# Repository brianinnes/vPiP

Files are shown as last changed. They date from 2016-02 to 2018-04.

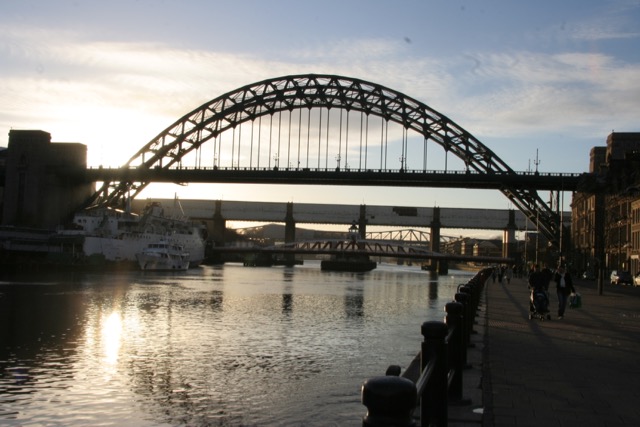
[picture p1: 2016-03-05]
testImages/TyneBridge.jpg

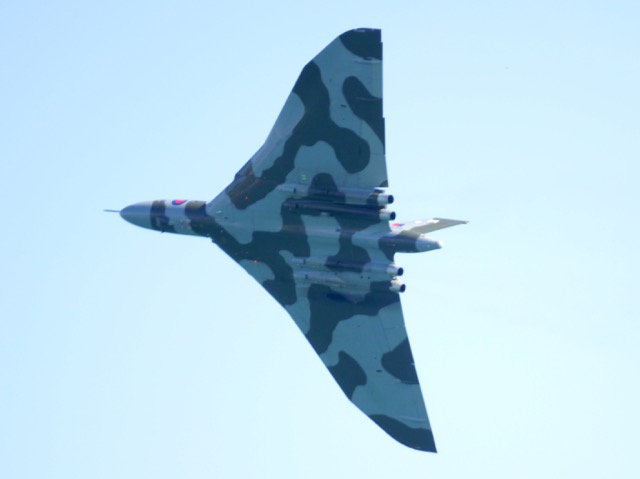
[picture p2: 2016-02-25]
testImages/Vulcan.jpg

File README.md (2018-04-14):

# vPiP
Driving a drawing machine from python

A python library targeted to run on a Raspberry Pi with accompanying Arduino code.  This code is intended to run on the driver board created by makeBournemouth

Links:  

- makeBournemouth [https://www.makebournemouth.com]()
- Controller board : [https://github.com/MarkJB/Eggbot-Spherebot-PyPlotter-Controller]()

Inspired by the Polargraph project [http://www.polargraph.co.uk]() and gocupi project [https://github.com/brandonagr/gocupi]()

To run this library you need Python installed with the Python Imaging Library fork, Pillow.  Installation instructions are here : [https://pillow.readthedocs.org/en/latest/installation.html]()  

sudo apt-get install libtiff5-dev libjpeg-dev zlib1g-dev libfreetype6-dev liblcms2-dev libwebp-dev tcl8.5-dev tk8.5-dev
pip install Pillow  

The C++ code for the Raspberry pi is build using Vagrant [https://www.vagrantup.com]() , which runs on most commonly used operating systems.

The make install command will automatically install the binary code on a Raspberry Pi, but relies on ssh auto login using a certificate.   
To setup auto login open a terminal and login to the vagrant build machine   
`vagrant up`   
`vagrant ssh`

Generate a certificate - on the raspberry pi:
`cd .ssh`   
`ssh-keygen -t rsa` accept all the default, DO NOT enter a password - leave blank     
`cat id_rsa.pub >> authorized_keys`  
`chmod 600 authorized_keys`  
`rm id_rsa.pub`  

Copy the certificate to the target Raspberry Pi using the following commands, replacing the host name (*raspberrypi.local*) with the host name or IP address of your pi:
`export REMOTE_PI=raspberrypi.local`   
`ssh pi@raspberrypi.local mkdir -p .ssh`   
`cat ~/.ssh/id_rsa | ssh pi@$REMOTE_PI 'cat >> .ssh/vagrant.rsa'`  
`ssh pi@$REMOTE_PI chmod 600 .ssh/vagrant.rsa`  
`ssh pi@$REMOTE_PI 'echo "Host vagrant" >> .ssh/config'`  
`ssh pi@$REMOTE_PI 'echo "Hostname vagrant.local" >> .ssh/config'`  
`ssh pi@$REMOTE_PI 'echo "IdentityFile ~/.ssh/vagrant.rsa" >> .ssh/config'`  

#Installing MQTT on a Raspberry Pi

You need an MQTT broker running and configured to run this software.  The MQTT broker can run on the Raspberry Pi.  To install run the following commands - this assumes running the latest Raspbian Stretch :  
- wget http://repo.mosquitto.org/debian/mosquitto-repo.gpg.key  
- sudo apt-key add mosquitto-repo.gpg.key  
- cd /etc/apt/sources.list.d/  
- sudo wget http://repo.mosquitto.org/debian/mosquitto-stretch.list
- sudo apt-get update
- sudo apt-get install -y mosquitto mosquitto-clients

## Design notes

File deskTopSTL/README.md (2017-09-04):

This folder contains the 3D printer files and information needed to build a desktop vPiP.  

The bill of materials is:  
- Raspberry Pi 3 model B  
- Built and populated [pi-2-stepper board](https://github.com/MarkJB/pi-2-stepper-board)  
- Arduino/Genuino compatible pro mini (ATmega 328p 3.3v 8MHz) - check PCB layout to ensure pro mini pins align with socket in PCB  
- Mini Servo - TowerPro SG90/92 or equivalent   
- 2 x ? Stepper drivers  
- ? voltage regulator  
- QTR-1RC Reflectance Sensor (pack of 2)  
- 2 x Stepper Motors (Nema 8 Bipolar 1.8º - 8HS11-0204S)  
- Vertical Blind, white plastic 2mm ball chain (2 meters)  
- A3 frameless whiteboard (297mm x 420mm x 4.5mm)  
- 6 x Bearings (603ZZ - 3mm x 9mm x 5mm)
- 12Volt (2A or higher) power supply

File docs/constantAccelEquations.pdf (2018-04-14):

## Control of stepper motors for vPiP drawing machine

This document sets out the approach for driving the stepper motors of the vPiP drawing machine within the architecture set out in the wiki. (https://github.com/brianinnes/vPiP/wiki/architecture)

The primary goal of the stepper driver to to produce a smooth motion to enable the fastest possible motion without making the print head start swinging or creating excessive movement within the cables driving the print head (which has been observed in existing implementations with v1 software).

In addition to the fast, smooth motion the algorithm should:
- keep the print head moving as fast as possible, reducing the loss of speed when transitioning between lines
- provide progress feedback to controlling process(es)
- allow interrupt commands to be sent to pause a drawing (say to allow a pen change), which will bring the drawing to a controlled stop at the end of a line, with the pen being raised from the paper (and optionally the drawing head homed). The drawing must be able to be resumed from exactly where it was paused.

## Kinematics - Algorithm for achieving smooth, fast motion

In version 1 of vPiP, the algorithm used constant acceleration to change velocity. This produces very high jerk values (rate of change of acceleration) at the transitions, which is a cause for stress on the system, which could be responsible for generation vibrations and additional movement in the control cables. To reduce the stress in the system and provide smoother motion of the print head then a constant jerk algorithm should be used.

Using Calculus to understand the equations of motion:
Looking at displacement (s) (distance travelled from start position s0):
- Velocity (v) is the first derivative of displacement with respect to time
- Acceleration (a) is the first derivative of velocity and the second derivative of displacement with respect to time (rate of change of velocity)
- Jerk (j) is the first derivative of acceleration and the third derivative of displacement with respect to time (rate of chance of acceleration)

Which gives us the kinematic equations:

Once the speed profile for the line has been calculated, then this needs to be translated into timer information to step each motor to create the line - this will be discussed later in the document.

Making each line a separate operation bringing the print head to a stop after each line is not ideal, so the algorithm also has to calculate the optimum speed to transition from 1 line to another. The angle between the lines will govern the amount of velocity that can be maintained during the transition and the appropriate amount of deceleration and acceleration should be calculated.

With short lines the acceleration/deceleration may take place over a number of line segments (such as curves implemented as a number of short line segments).

## s = s0 + v0t+ ¹

2 a0t

2

+ ¹
6 jt

3

## v = v0 + a0t+ ¹

2 jt

2

## a = a0 + jt

## Example data

With between motor driving wheels : | 344mm
Distance to top left corner of board : | x = 22mm; y = 36mm
Distance to paper location from top of board : | x = 10mm; y = 40mm
therefore distance from (0,0) measuring point = 22+10 ; 36 + 40 = (32mm, 76mm)
Paper Size = A4 portrait : | x = 210mm; y = 297mm,
therefore paper bottom right corner at 32 + 210; 76+297 = (242mm, 374mm) Paper margin = 10mm, so drawing area is (42mm, 86mm) to (232mm, 364mm)
Drawing grid is 10,000 along x and | along y
therefore1 point on the coordinate grid is
Maximum Velocity = 30 mm/ds (millimeters per decisecond : decisecond = 0.1 seconds) Maximum Acceleration = 10 mm/ds²
Maximum Jerk = 5 mm/ds³

Line in coordinates (100,9000) -> (9000,100)
Line in mm = (42+100*0.019, 86+9000*0.019) -> (42+9000*0.019, 86+100*0.019) = (43.9,257) -> (213,87.9)

Line length =

## Line Geometry

To calculate the formula for the line from (x1, y1)->(x2, y2):

where m is the gradient of the line and c is where the line crosses the x=0 axis (unless the line is vertical),

so if x1 ≠ x2:

Plugging in one of the coordinate (100, 9000):

To calculate a point (x, y) a specified distance (d) from the first point (x1, y1) along a line (x1, y1)→(x2, y2):

### 10000 * ²⁷⁷

190 = 14578.947
190
10000 = 0.019mm

## Δx² + Δy²

(213 − 43.9)

2 + (257 − 87.9)

2
169.1² + 169.1²
57189.62 = 239.1435mm

## y = m x + c

m = y2 − y1
x2 − x1

## y = m x + c y − m x = c c = y − m x

m = y2 − y1
x2 − x1
m = 100 − 9000

9000 − 100 = −8900
8900 = − 1

## c = y − m x

c = 100 − −1 * 9000 = 9100

x = x1− d * (x1 − x2)
linelength

## y = m x + c

## 7-phases for constant acceleration

Using constant jerk to control the rate of change of acceleration produces 7 stages for a line when the line needs to accelerate and decelerate and there is sufficient distance, velocity change and time to allow all 7 stages:

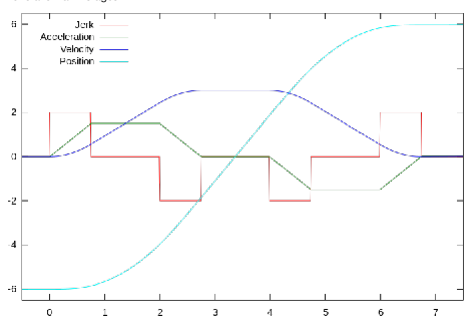
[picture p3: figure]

Acceleration time = ∆t1 + ∆t2 + ∆t3 Constant velocity time = ∆t4
Deceleration time = ∆t5 + ∆t6 + ∆t7

### Phase 1 - Increasing Acceleration

At t0:
j0 = jmax = 5
a0 = a0 = 0
v0 = v0 = 0
s0 = 0
| 1 = t0 → t 1 | Δt2 = t 1 → t2 | 3 t | Δt 4 = t3 → t 4 | 4 → t Δ 5 t3 = t2 → t Δ | Δt6 = t5 → t6 | Δt7 = t6 → t Δ 7 t5 = t
Jerk - j | j max | 0 | −j max | 0 | −j max | 0 | j max
Acceleration - a | increasing | amax | decreasing | 0 | increasing deceleration | −amax | decreasing deceleration
Velocity - v | increasing | increasing | increasing | vmax | decreasing | decreasing | decreasing
Displacement - s | increasing | increasing | increasing | increasing | increasing | increasing | increasing

Δt

## 1 = Δt3 = t

1 = amax
jmax

= 10
5 = 2

Note: at t = t1:

plugging in the sample numbers gives:

at end of phase (t1) we have:

### Phase 2 - Constant Acceleration

At t1
j1 = 0
a1 = amax
v1 = vt1 = 10 v2 = vmax - v1 = 30 - 10 = 20 s1 = st1 = 6.667

at end of phase (t2) we have:

## t0 < t ≤ t

1

## at = j

maxt

## vt = v0 + a0t+ ¹

2 j

maxt

2

## st = v0t+ ¹

2 a0t

2 + ¹
6 j

maxt

3

## v1 = v0+ a2

s
(2jmax)

## t0 < t ≤ t

1

## vt = 0 + 0t+ ¹

2 5t

2 = 5t2
2

## st = 0t+ ¹

2 0t

2 + ¹
6 5t

3 = 5t

3
6

## at1 = amax = 10mm /ds²

vt1 = 5t2

2 = 5 * 2²
2 = 20

## 2 = 10mm /ds

or

## vt1 = 0+ ¹⁰²

2 * 5 = 100
10 = 10

st1 = 5t

3

6 = 5 * 2³
6 = 40
6 = 6.667mm

## v2 = v1 + amaxΔt2 v2 − v1 = amaxΔt2

v2 − v1
amax

= Δt2

Δt2 = vmax − 2v1
amax
Δt2 = 30 − 2 * 10

10 = 30 − 20 10 = 1

t

1 < t ≤ t2

## vt = v1 + amaxt = 10 + 10t

## st = v1t+ ¹

| 2 amaxt

## 2 = 10t + ¹⁰

2 t

2 = 10t + 5t

2

### Phase 3 = Decreasing Acceleration

At t2:
j2 = -jmax
a2 = 10mm/ds²
v2 = 20mm/ds
s2 = s1 + ∆s2 = 6.667 + 14 = 20.667mm

plugging in the example numbers gives:

at the end of phase 3 we have :

### Phase 4 - Constant velocity

At t3:
j3 = 0
a3 = 0
v3 = vmax = 30mm/ds²
s3 = s1 +∆s2 +∆s3 = 6.667+15+33.333 = 55mm = Distance to accelerate to max velocity t3 = ∆t1+∆t2+∆t3 = 2+1+2 = 5ds = Time to accelerate to max velocity

With symmetric acceleration and deceleration, distance and time to decelerate will equal time to accelerate, so for phase 4, the constant velocity phase:

Distance to travel in phase 4 = Total Distance - 2*s3 = 239.1435-2*55 = 239.1435-110 = 129.1435

so plugging in the test data we have

## vt2 = 10 + 10 * 1 = 20mm /ds Δst2 = 10 * 1 + 5 * 1² = 10 + 5 = 15mm

## t2 < t ≤ t3 at = j

maxt

## vt = v2 + a2t+ ¹

2 j

maxt

2

## st = v2t +

1
2

a2t

2

+ ¹
6 j

maxt

3

## t0 < t ≤ t

1

## vt = 20 + 10t+ ¹

2 − 5t

## 2 = 20 + 10t − ⁵t2

2

## st = 20t+ ¹

2 10t

2 + ¹
6 5t

## 3 = 20t + ¹⁰

2 t

2 − ⁵t

3
6
at3 = 0

## vt3 = 20 + 10 * 2− ⁵ * 2²

2 = 20 + 20 − ²⁰

## 2 = 30mm /ds Δst3 = 20 * 2+ ¹⁰ * 2²

2 − ⁵ * 2³
6 = 40 + 20 − ⁴⁰
6 = 40 − 6.667 = 33.33mm

## t3 < t ≤ t

4
st = vmaxt

### Phase 5 - Increasing Deceleration

At t0:
j4 = -jmax
a4 = a4
v4 = v4
s4 = s4

### Phase 6 - Constant Deceleration

At t1
j1 = 0
a1 = amax
v1 = v1 v2 = vmax - v1
s1 = s1

### Phase 7 = Decreasing Deceleration

At t2:
j2 = jmax
a2 = amax
v2 = v2
s2 = s2

129.1435 = 30Δt
4
Δt

4 = 129.1435
30 = 4.3048ds

Δt

## 5 = Δt7 = t

5 = amax
jmax
t

4 < t ≤ t
5

## vt = v4 + a4t − 1

2 j

maxt

2

## st = v4t − 1

2

a4t

2 − 1
6 j

maxt

3

t

5 < t ≤ t6

## v2 = v1 + amaxΔt2 v2 − v1 = amaxΔt2

v2 − v1
amax

= Δt2

## Δt2 = vmax − 2v1

amax

## vt = v1 + amaxt

## st = v1t +

1
2

amaxt

2

### How to deal with short lines

The 7 phases defined above requires a line to be of a certain length to allow all 7 phases to run. As line become shorter then phase 4 will reduce until it no longer contributes to the movement, so the line becomes phases 1, 2, 3, 5, 6, 7. This is the shortest line that will reach maximum velocity from a standing start and coming to a stop at the end of the line.

If the line is shorter then phases 2 and 6 will reduce symmetrically, but this will reduce the velocity reached whilst drawing the line (maximum rate of acceleration will still be reached). As the line shortens then eventually phases 2 and 6 will contribute nothing to the line, so the line becomes phases 1, 3, 5, 7. This is the shortest line that will reach maximum acceleration from a standing start and coming to a stop at the end of the line.

If the line is still shorter then phases 1, 3, 5 and 7 will reduce symmetrically, but this will prevent maximum acceleration from being achieved whilst drawing the line.

## Combining multiple lines

It is not always desirable to start a line from stop and coming to a stop at the end of every line. It is often possible to combine lines to maintain some velocity during the transition from one line to the next. The angle between the lines determines how much velocity can be carried during the transition from one line to the next.

[See https://onehossshay.wordpress.com/2011/09/24/improving_grbl_cornering_algorithm/]

For a given angle θrad the maximum velocity is given by:

Given the 3 points that define 2 lines (x1, y1)->(x2, y2)->(x3, y3) that join at (x2, y2), you can use vectors to find the angle between the two lines.

## t6 < t ≤ t7 vt = v2 + a2t − 1

2 j

maxt

2

## st = v2t +

1
2

a2t

2 − 1
6 j

maxt

3

| t0 | t1 | t2 | t3 | t4 | t5 | t6 | t7
t (ds) | 0 | 2 | 3 | 5 | 9.3048 | 11.3048 | 12.3048 | 14.3048
a (mm/ds²) | 0 | 10 | 10 | 0 | 0 | -10 | -10 | 0
v (mm/ds) | 0 | 10 | 20 | 30 | 30 | 20 | 10 | 0
d (mm) | 0 | 6.667 | 21.667 | 55 | 184.1435 | 217.4768 | 232.4768 | 239.1435

vjunction = amaxR

## R = 1 − cos(θrad)

2

Note: | is the length of the vector , which is the length of the line (x1,y1)->(x2,y2) and is the length of the vector , which is the length of the line (x2,y2)->(x3,y3).

Combining the 2 formula removes the cos function:

Using this formula a number of line segments can be combined to form a continuous movement. The motion needs to come to a complete stop when the pen needs to be raised or when the angle between lines is too small. Whilst drawing the composite line any of the 7 phases may cross multiple line segments and there may need to be additional acceleration or deceleration phases within the composite line depending on line segment joint angles.

This requires a planning algorithm to:
- Combine individual lines into line segments
- Determine maximum joint velocities
- Map the composite line into a series of motion phases

### Map lines into a series of motion phases

Turning the line segments into one of the 7 phases of motion (as described above). For any line there are a number of possible options:

1. The initial and final velocities are low enough and there is sufficient distance to travel to go through all 7 phases
2. The initial velocity is too hight, so only time for phases 1 and 3 while accelerating
3. The final velocity is too high to go through all deceleration phases, so only phases 5 and 7.
4. The line is too short to allow phase 4 (max velocity may not be possible), phases 1,2,3,5,6,7
5. The line is too short to allow constant acceleration phases, only phases 1,3,5,7
6. The line is too short to accelerate to reach the final velocity. Only phases 1,3 or 1,2 and 3. The length will determine how near the final velocity can be attained, but the line may complete with a slower than planned maximum velocity.
7. The line is too short to decelerate to meet the required final velocity. The start velocity to meet then required final velocity to be reach needs to be calculated then the previous line needs to be altered to finish at the required lower velocity so the current line can decelerate to the required final velocity.

## u ⃗= (a1, b1), v ⃗= (a2, b2)

## a1 = x2 − x1, b1 = y2 − y1, a2 = x3 − x2, b2 = y3 − y2 cos(π − θrad) = ( u ⃗⋅ v ⃗)

(∥ u ∥⃗⋅∥ v ∥⃗)

## cos(θrad) = -1 * ( u ⃗⋅ v ⃗)

(∥ u ∥⃗⋅∥ v ∥⃗)
cos(θrad) = -1 * | (a1a2 + b1b2)
| ( a12 + b1 2 * a22 + b2

2)
∥ u ⃗∥ | u ⃗
∥ v ⃗∥ | v ⃗

vjunction = amax *

1 + (

(a1a2 + b1b2)

( a12 + b1

2 * a22 + b2

2)

)

2

## Turning the planned line into vPip movement

Up to now this document has focussed on calculating the motion for the lines. Once the lines have been planned and the set of motion phases has been calculated to create the lines this needs to be mapped into a set of stepper instructions for the 2 motors on a vPiP drawing machine. The planning and calculations required to create the motion phases is too complex for a small 8-bit processor, such as the Arduino that drives the steppers, so the computation is performed on the Raspberry Pi then a series of instructions is passed to the Arduino to control the stepper drivers.

There are a number of possible approaches for the communication between the Raspberry Pi and the Arduino. There may have to be a trade off between accuracy and maximum achievable data rate between the Raspberry Pi and the Arduino.

In version 2 there are options to look at using different communication mechanisms between the Raspberry Pi and the Arduino:
- Serial (UART)
- I²C - (cannot run at maximum speed, as there is a hardware bug in the Raspberry Pi, which the Arduino cannot cope with)
- SPI - (not enabled with the current version of the vPIP controller circuit board)

Other options that could be considered include modifying the module used to control the vPiP plotter (ESP32, NXP or ST Micro arm based module - these give 32-bit processing capability, so may remove the need to split the calculation and motor driving, or could leave the planning on the Pi or a laptop/workstation, but move the stepper calculations to the vPiP controller board)

These decisions need to be made up front as the outcome will define the vPiP controller board interface and API.

### Time Slicing

In version 1 of vPiP the Raspberry Pi to Arduino communication is based on a series of equal time slices, where the number of steps required for each motor is calculated and sent over the serial link to the Arduino. This produces an approximation of the calculated motion as for each time slice the required steps are spaced equally over the time rather than being at the exact calculated time interval.

Using time slices we have all the equations we need to determine the position the drawing head (displacement - s) should be at for each time slice interval, so for a given time t we can calculate the displacement (s) then calculate the coordinate in mm coordinate space. This can then be plugged into the equations that calculate the length of the control cables from each stepper motor moving the drawing head, and then from there the number of steps each motor should be at from the home position. The smaller the time slice the more accurate the step timing, but the higher the data rate between the Raspberry Pi and the Arduino.

### Fully accurate time steps

This is the most desirable outcome, as each stepper motor will be driven at exactly the correct time (allowing for CPU clock speed). For each step of each motor calculate the time the step should be taken, then combine the step times for each motor to create a stream of delays then step instructions (L step, R step or both step). This will require a high data rate (need to calculate) to pass these instructions to the stepper controller, and may need a high CPU clock speed on the controller to be able to parse the stream and implement the stepper controls.

One of the issues with this approach is the mathematics needed to calculate the time for each step, as phases 1, 3, 5 and 7 involve cubic equations, which need to be solved for t, as s, v, a and j will be known:

[TODO research algorithms for solving cubic functions - maybe https://stackoverflow.com/questions/1829330/solving-a-cubic-equation (https://stackoverflow.com/questions/1829330/solving-a-cubic-equation) or https://www.codeproject.com/Articles/798474/To-Solve-a-Cubic-Equation (https://www.codeproject.com/Articles/798474/To-Solve-a-Cubic-Equation) provides a solution?]

## st = v2t +

1
2

a2t

2

+ ¹
6 j

maxt

3

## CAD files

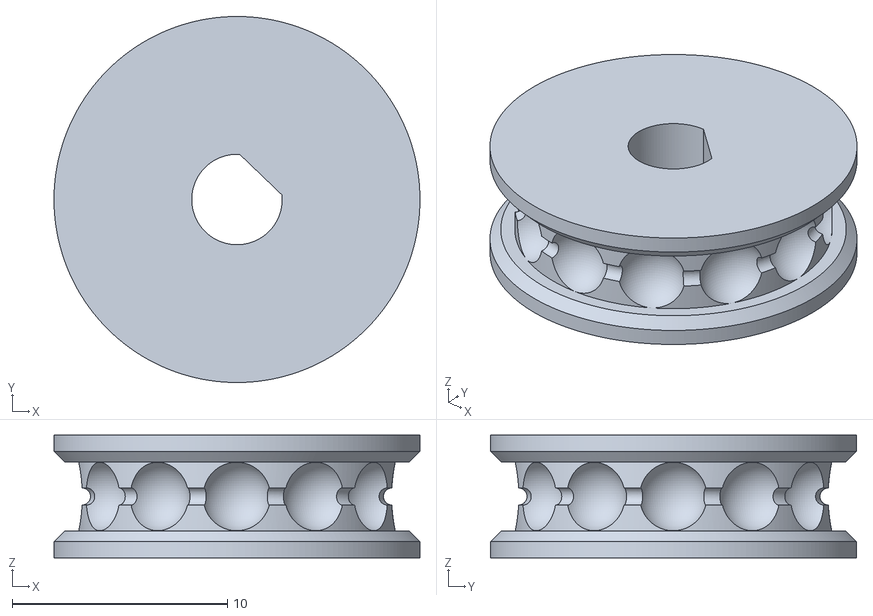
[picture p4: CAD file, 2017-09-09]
deskTopSTL/Motor cog (1).stl
17.0 x 17.0 x 5.69

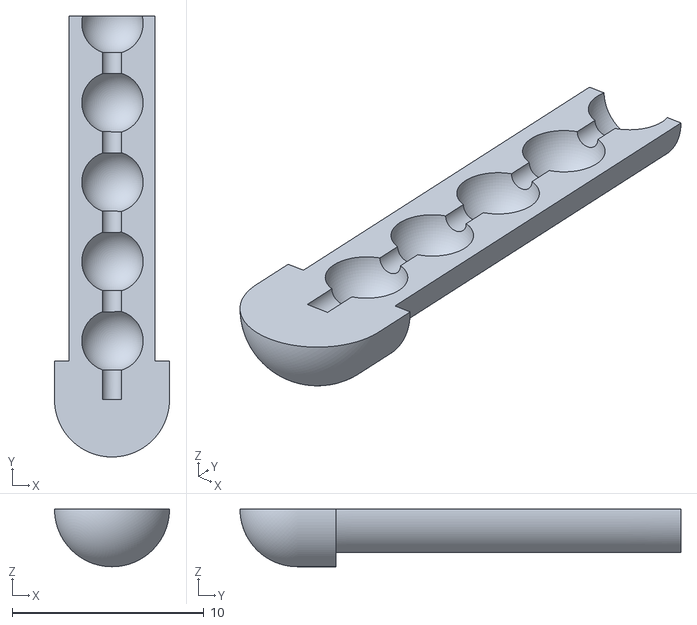
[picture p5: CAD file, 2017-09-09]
deskTopSTL/HangarCableGrab.stl
6.00 x 23.0 x 3.00

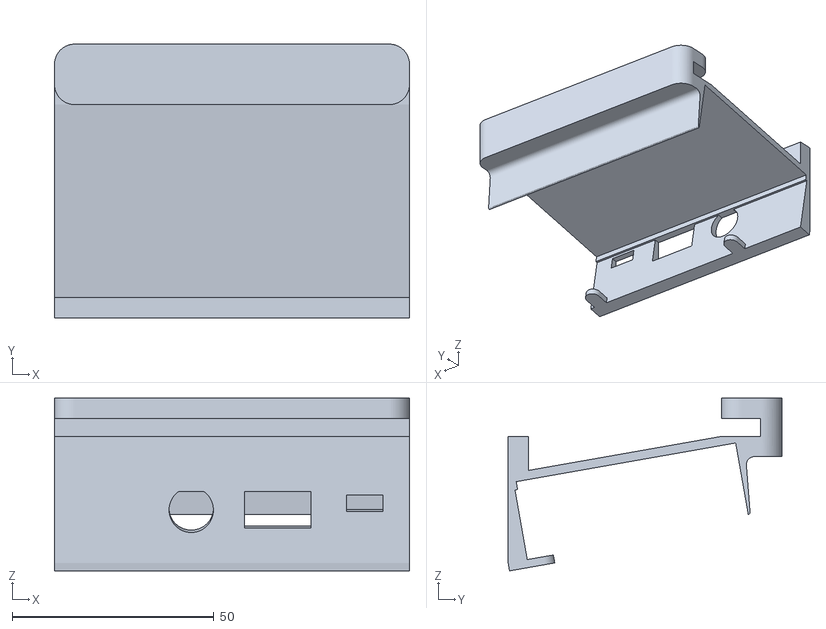
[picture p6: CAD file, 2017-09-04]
deskTopSTL/Pi Holder.stl
88.0 x 67.9 x 42.8

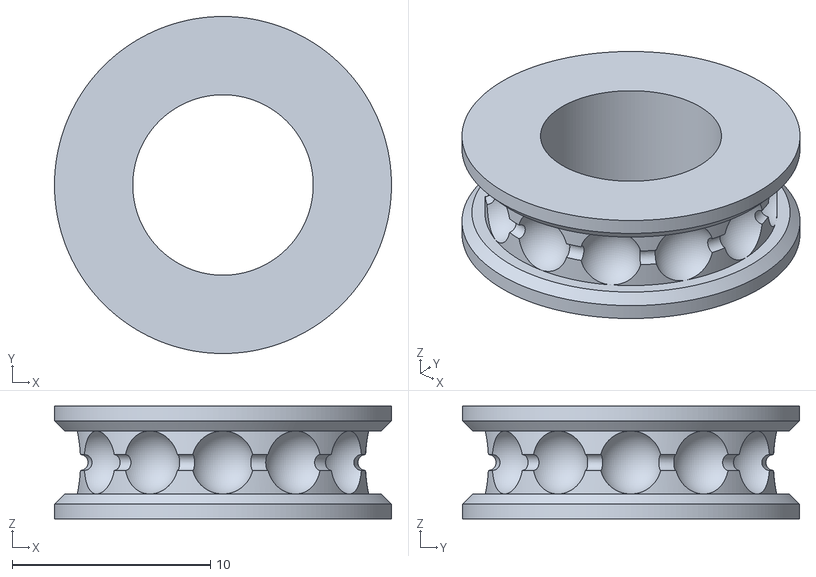
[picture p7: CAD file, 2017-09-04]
deskTopSTL/BearingPullyWheel.stl
17.0 x 17.0 x 5.69

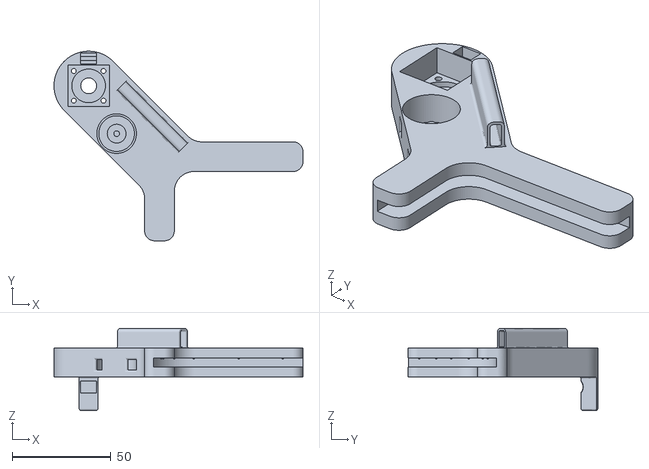
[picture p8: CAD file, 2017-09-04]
deskTopSTL/TopRArmBearing.stl
125.8 x 95.8 x 41.5

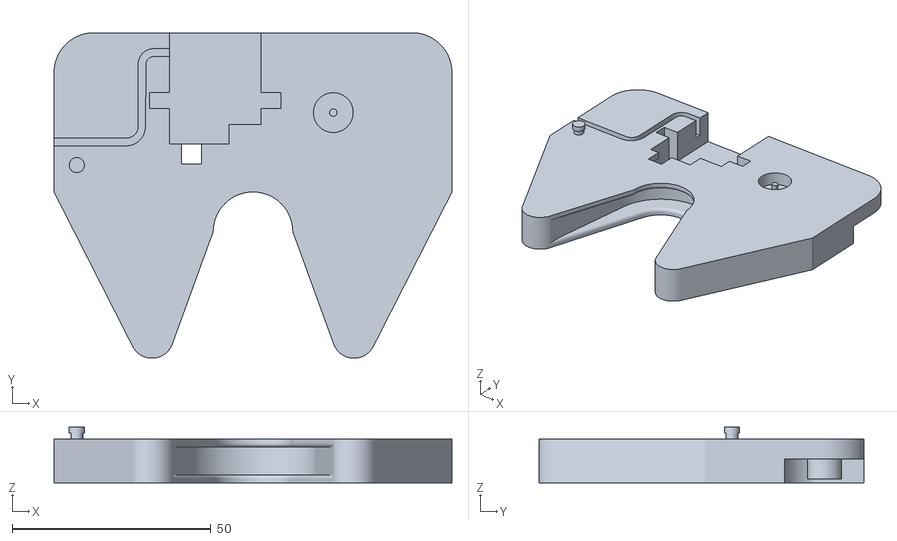
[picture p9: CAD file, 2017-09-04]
deskTopSTL/GondolaBody.stl
100.0 x 81.8 x 14.0

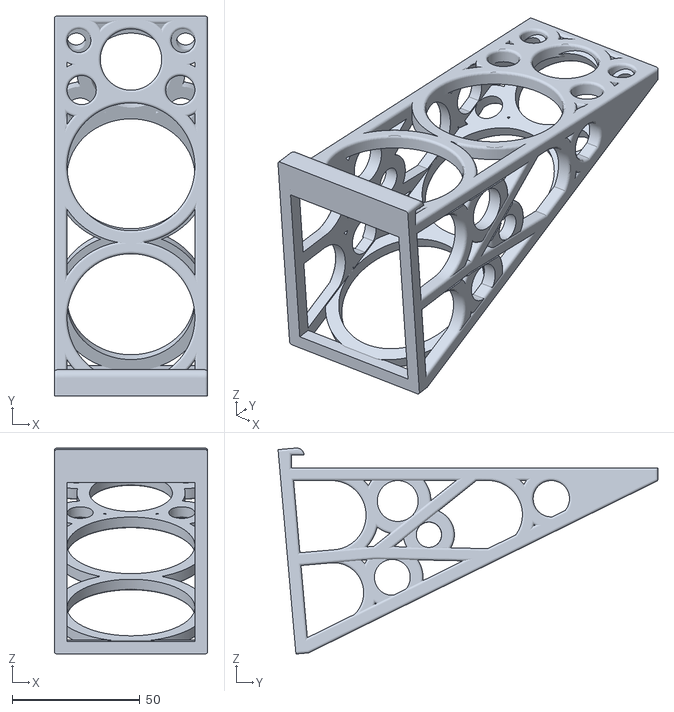
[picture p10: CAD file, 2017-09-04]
deskTopSTL/Stand.stl
60.0 x 148.7 x 80.6

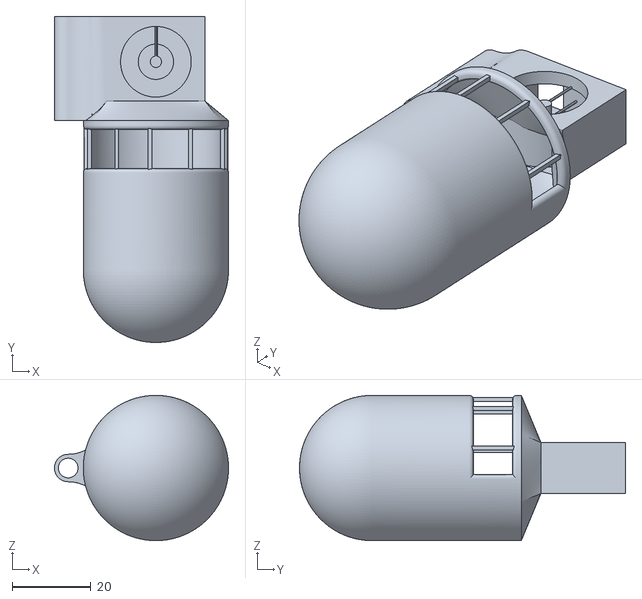
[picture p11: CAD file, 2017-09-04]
deskTopSTL/HangarLeftBearing.stl
44.3 x 83.0 x 37.0

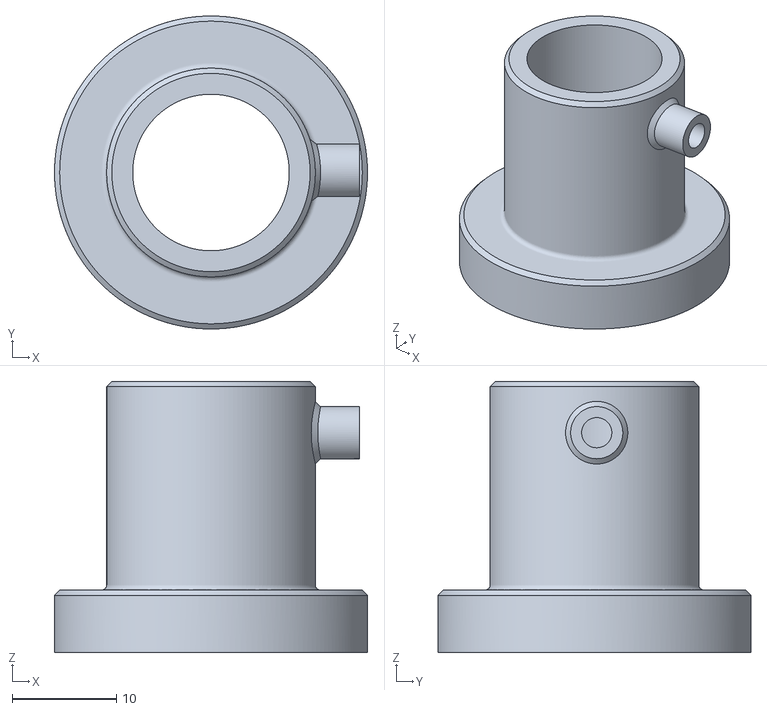
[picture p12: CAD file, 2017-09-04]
deskTopSTL/PenHolder (1).stl
30.0 x 30.0 x 26.0

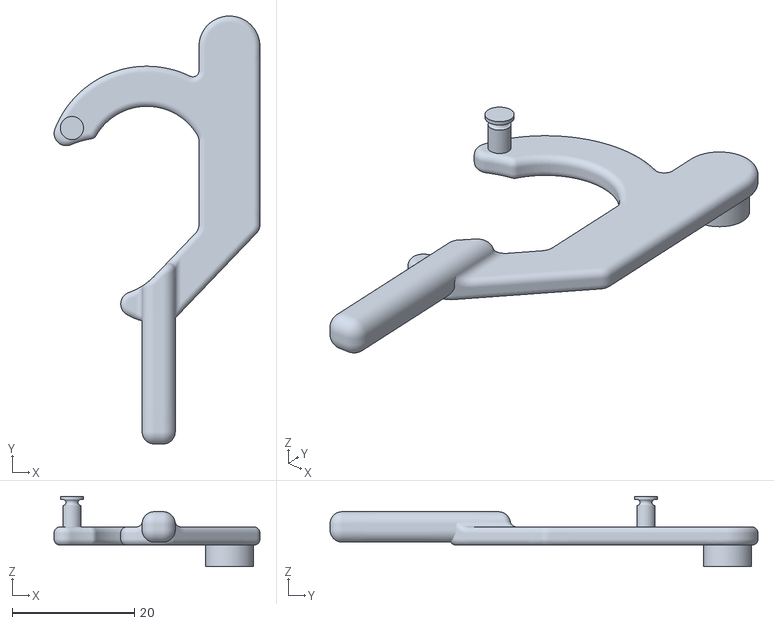
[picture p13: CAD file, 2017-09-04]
deskTopSTL/PenHolderClamp.stl
33.7 x 70.1 x 11.5

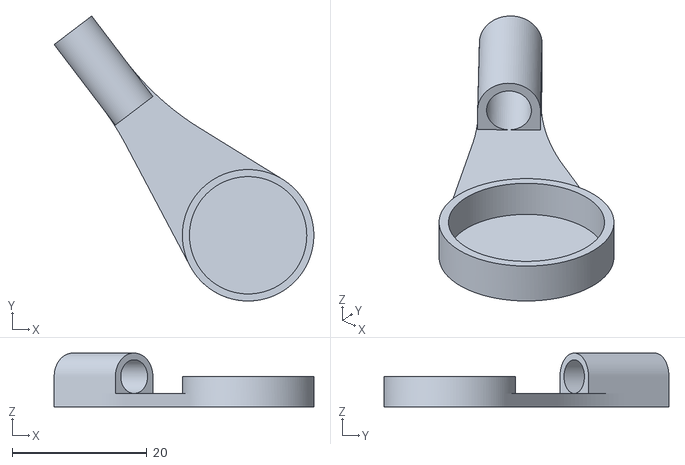
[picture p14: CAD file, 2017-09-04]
deskTopSTL/CordArm.stl
38.5 x 42.3 x 8.00

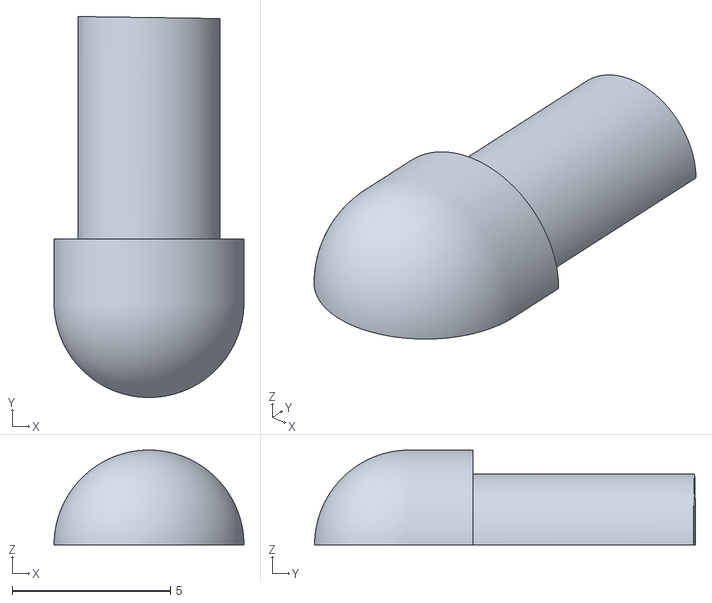
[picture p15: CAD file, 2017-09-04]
deskTopSTL/CableGrab] (1).stl
6.00 x 12.0 x 3.00

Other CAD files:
deskTopSTL/TopLeftArmBearing.stl
deskTopSTL/HangarRightBearing.stl

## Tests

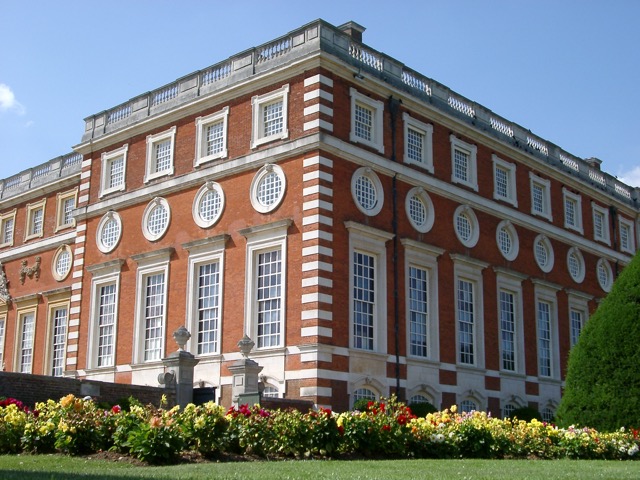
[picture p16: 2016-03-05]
testImages/HamptonCourt.jpg

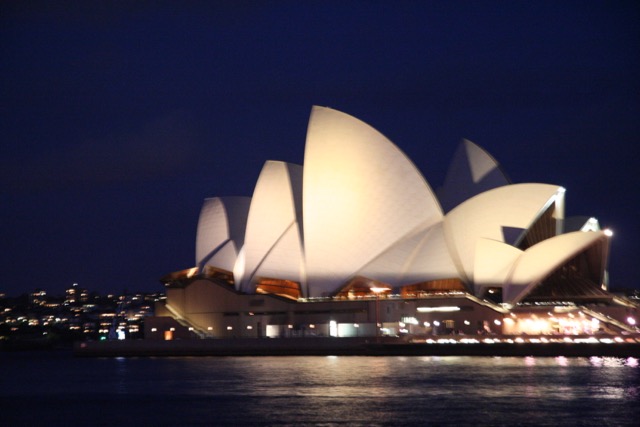
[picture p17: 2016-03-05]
testImages/SydneyOperaNight.jpg

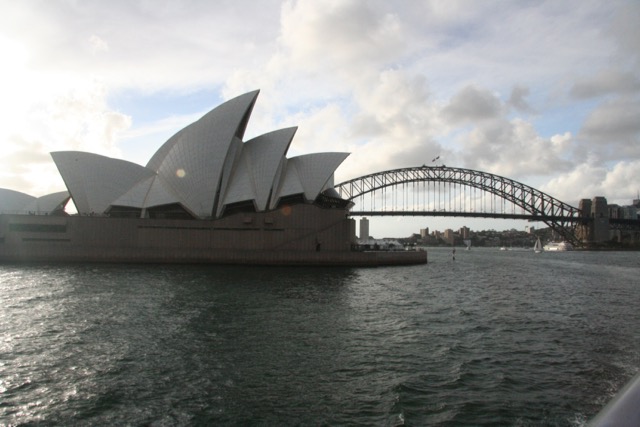
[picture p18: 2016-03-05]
testImages/SydneyOpera.jpg

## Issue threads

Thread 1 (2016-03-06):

Servo height settings are ignored

MarkJB, 2016-03-06:
Running test2.py and modifying the config values for penUp and penDown doesn't appear to have any effect on where the servo goes.

I tried a range of values but it doesn't change the servo positions.

I set them both to 0 and its still the same.

I changed the values in the Arduino firmware from:

`const long PENUP_ANGLE = 170;
const long PENDOWN_ANGLE = 85;`

to

`const long PENUP_ANGLE = 125;
const long PENDOWN_ANGLE = 63;`

and the positions changed.

This was with Python 2.7.11 on Win7x64

MarkJB, 2016-03-06:
I don't know why there aren't line breaks in the above... Markdown never works properly for me.

MarkJB, 2016-03-06:
If you are wondering the python is seeing the config:

C:\Users\Mark\Documents\GitHub\pycupi\python>c:\Python\Python27-11\python.exe test2.py
Polargraph __init__
Config is being read from C:\Users\Mark/.polargraph/config.cfg

***** System configuration *****
configured = True
penSize = 0.5
machineWidth = 610
machineHeight = 1010
mmPerRev = 92.0
stepsPerRev = 200
stepMultiplier = 8
serialPort = COM10
timeSliceUS = 2048.0
baud = 57600
motorAccel = 0.2
motorMaxSpeed = 100.0
penUp = 0
penDown = 0
homeX = 305
homeY = 120
polarDraw = True
size = A3p
width = 420
height = 297
posX = 83
posY = 398
margin = 20
pixelsX = 5000
pixelsY = 3381
rotate = False
stepsSizeMM = 0.0575
stepsPerValue = 15.75
MaxSpeedMMs = 100.0
AccelerationMMs2 = 500.0
screenX = 5000
screenY = 3381
showImage = False
saveImage = False
Coord handler running

Step handler running
Connected to Polargraph

Polargraph __exit__

brianinnes, 2016-03-06:
Ah, I forgot about this - it is on the todo list.  The gocupi protocol currently does not provide any options to send config data from the controlling device to the Arduino.  I have a cunning plan to use the reset command to be able send additional config data whilst still being able to run against a true gocupi system (where the config for micro-steps, timing window and penup/pen down angles all need to be set in Arduino code, and where applicable also in the controller code).

brianinnes, 2017-09-10:
Implemented in v0.2 in commit 37af6e78de0516c9e5431b9141468f667e025eab

MarkJB, 2017-09-10:
Liking the config!

Very cool that you can define the hardware pins from the controller rather than the firmware.

Am I right in thinking the config is extensible just be virtue of adding items to the config stuct and then send the relevant data (in order)?

brianinnes, 2017-09-10:
Yes, so long as the structure on the Pi and the Arduino are kept in sync you can add additional attributes and they will be sent to the Arduino on startup - the entire structure is sent to the Arduino.

You need to be aware of the structure packing differences between 64 and 8 bit architectures - hence the pack compiler instruction.

MarkJB, 2017-09-11:
One thing just struck me, https://github.com/brianinnes/vPiP/issues/16 says v2 must work with existing hardware which would mean being able to use serial if I2C isn't available/connected.

Closed 2017-09-10.

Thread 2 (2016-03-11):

Python processes don't die

MarkJB, 2016-03-11:
I was running test1.py and had to kill it (ctrl-c a couple of times) which left two processes running.

A second run of test1.py was killed leaving another 2 processes.

Had to kill them manually.

I was running commit:

f0d0eef793cf2f2e25163ef0d5ac13d7b2944c05
Date:   Wed Mar 9 21:28:13 2016 +0000
Moved from using threads to use multiprocesses to get round single process restriction and enable use of multi-core raspberry pi

brianinnes, 2017-04-27:
Version 2 will replace the need for multiple python processes

Closed 2017-04-27.

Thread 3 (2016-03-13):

Steppers are glitchy when setShowDrawing & setPlotting are both True

MarkJB, 2016-03-13:
Running test1.py with:

```
p.setShowDrawing(True)
#p.setSaveDrawing(True)
p.setPlotting(True)
```

or

```
#p.setShowDrawing(True)
p.setSaveDrawing(True)
p.setPlotting(True)
```

This doesn't happen if just have setPlotting true.

The steppers are stop start and there is lots of output on the console.

I captured some (below) and in doing so caused a keyboard interrupt (ctrl-c) and the output stopped and the steppers started working normally.

Step handler thread exception : <type 'exceptions.OSError'>
  File "/home/pi/pycupi/python/Pylargraph/serialHandler.py", line 106, in _stepHandlerThread
    dataRead = self.serialPort.read()
  File "/usr/lib/python2.7/dist-packages/serial/serialposix.py", line 453, in read
    buf = os.read(self.fd, size-len(read))
Step handler thread exception : <type 'exceptions.OSError'>
  File "/home/pi/pycupi/python/Pylargraph/serialHandler.py", line 106, in _stepHandlerThread
    dataRead = self.serialPort.read()
  File "/usr/lib/python2.7/dist-packages/serial/serialposix.py", line 453, in read
    buf = os.read(self.fd, size-len(read))
Step handler thread exception : <type 'exceptions.OSError'>
  File "/home/pi/pycupi/python/Pylargraph/serialHandler.py", line 106, in _stepHandlerThread
    dataRead = self.serialPort.read()
  File "/usr/lib/python2.7/dist-packages/serial/serialposix.py", line 453, in read
    buf = os.read(self.fd, size-len(read))
Step handler thread exception : <type 'exceptions.OSError'>
  File "/home/pi/pycupi/python/Pylargraph/serialHandler.py", line 106, in _stepHandlerThread
    dataRead = self.serialPort.read()
  File "/usr/lib/python2.7/dist-packages/serial/serialposix.py", line 453, in read
    buf = os.read(self.fd, size-len(read))
Step handler thread exception : <type 'exceptions.OSError'>
  File "/home/pi/pycupi/python/Pylargraph/serialHandler.py", line 106, in _stepHandlerThread
    dataRead = self.serialPort.read()
  File "/usr/lib/python2.7/dist-packages/serial/serialposix.py", line 453, in read
    buf = os.read(self.fd, size-len(read))
Step handler thread exception : <type 'exceptions.OSError'>
  File "/home/pi/pycupi/python/Pylargraph/serialHandler.py", line 106, in _stepHandlerThread
    dataRead = self.serialPort.read()
  File "/usr/lib/python2.7/dist-packages/serial/serialposix.py", line 453, in read
    buf = os.read(self.fd, size-len(read))
Step handler thread exception : <class 'serial.serialutil.SerialException'>
  File "/home/pi/pycupi/python/Pylargraph/serialHandler.py", line 106, in _stepHandlerThread
    dataRead = self.serialPort.read()
  File "/usr/lib/python2.7/dist-packages/serial/serialposix.py", line 460, in read
    raise SerialException('device reports readiness to read but returned no data (device disconnected?)')
Step handler thread exception : <class 'serial.serialutil.SerialException'>
  File "/home/pi/pycupi/python/Pylargraph/serialHandler.py", line 106, in _stepHandlerThread
    dataRead = self.serialPort.read()

If setPlotting() should never be true when setShowDrawing() or setSaveDrawing() are True - can this not be done automatically?

brianinnes, 2017-04-27:
fixed with #13

Closed 2017-04-27.

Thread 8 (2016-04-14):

Arduino Motorshield v2.3

5p4m3r, 2016-04-14:
Hi,
I am trying to get your stepperdriver sketch to work with the arduino motorshield v2.3.
and i am stuck. Obviously I am missing something very basic, but since i am new to python and arduino so i should start asking.
I hope it is the right spot if not just point me to the right direction.

so here is my sketch:

`//ADAFRUIT_MOTORSHIELD_V2.3`
```
#include <Wire.h>
#include <Adafruit_MotorShield.h>
#include <Adafruit_PWMServoDriver.h>
#include <AccelStepper.h>

const int stepType = MICROSTEP;

Adafruit_MotorShield AFMS = Adafruit_MotorShield();
Adafruit_StepperMotor *afMotorAleft = AFMS.getStepper(200, 1); //left M1 M2
Adafruit_StepperMotor *afMotorBright = AFMS.getStepper(200, 2); //right M3 M4

void forwarda() { afMotorAleft->onestep(FORWARD, stepType); }
void backwarda() { afMotorAleft->onestep(BACKWARD, stepType); }
void forwardb() { afMotorBright->onestep(FORWARD, stepType); }
void backwardb() { afMotorBright->onestep(BACKWARD, stepType); }
AccelStepper motorA(forwarda, backwarda);
AccelStepper motorB(forwardb, backwardb);

// comment out to disable PENUP support
#define ENABLE_PENUP

// Constants and global variables
// --------------------------------------
const int LED_PINS_COUNT = 4;
const int LED_PINS[LED_PINS_COUNT] = {
  10,11,12,13}; // the pins of all of the leds, first 3 are status lights, 4th is receive indicator

#ifdef ENABLE_PENUP
#include <Servo.h>
Servo penUpServo;
char penTransitionDirection; // -1, 0, 1
const long PENUP_TRANSITION_US = 524288; // time to go from pen up to down, or down to up
const int PENUP_TRANSITION_US_LOG = 19; // 2^19 = 524288
const long PENUP_COOLDOWN_US = 1250000;
const long PENUP_ANGLE = 170;
const long PENDOWN_ANGLE = 85;
#endif

const unsigned int TIME_SLICE_US = 2048; // number of microseconds per time step
const unsigned int TIME_SLICE_US_LOG = 11; // log base 2 of TIME_SLICE_US
const unsigned int POS_FACTOR = 8; // fixed point factor each position is multiplied by
const unsigned int POS_FACTOR_LOG = 3; // log base 2 of POS_FACTOR, used after multiplying two fixed point numbers together

const char RESET_COMMAND = 0x80; // -128, (128) command to reset
const char PENUP_COMMAND = 0x81; // -127, (129) command to lift pen
const char PENDOWN_COMMAND = 0x7F; // 127,(127) command to lower pen

const unsigned int MOVE_DATA_CAPACITY = 1024;
char moveData[MOVE_DATA_CAPACITY]; // buffer of move data, circular buffer
unsigned int moveDataStart = 0; // where data is currently being read from
unsigned int moveDataLength = 0; // the number of items in the moveDataBuffer
unsigned int moveDataRequestPending = 0; // number of bytes requested

char leftDelta, rightDelta; // delta in the current slice
long leftStartPos, rightStartPos; // start position for this slice
long leftCurPos, rightCurPos; // current position of the spools

unsigned long curTime; // current time in microseconds
unsigned long sliceStartTime; // start of current slice in microseconds

// setup
// --------------------------------------
void setup() {
  Serial.begin(57600);
  Serial.setTimeout(0);

//ADAFRUIT_MOTORSHIELD_V2.3
  AFMS.begin();  // create with the default frequency 1.6KHz

  // setup pins
  for(int ledIndex = 0; ledIndex < LED_PINS_COUNT; ledIndex++) {
    pinMode(LED_PINS[ledIndex], OUTPUT);
    digitalWrite(LED_PINS[ledIndex], HIGH);
  }

#ifdef ENABLE_PENUP
  penUpServo.attach(9);
  penUpServo.write(PENUP_ANGLE);
  delay(1000);
  penUpServo.write(PENDOWN_ANGLE);
  delay(1000);
  penUpServo.write(PENUP_ANGLE);
#endif

  ResetMovementVariables();

  delay(500);
  UpdateReceiveLed(false);
  UpdateStatusLeds(0);
}

// Reset all movement variables
// --------------------------------------
void ResetMovementVariables()
{
  leftDelta = rightDelta = leftStartPos = rightStartPos = leftCurPos = rightCurPos = 0;
  sliceStartTime = curTime;

#ifdef ENABLE_PENUP
  penTransitionDirection = 0;
  penUpServo.write(PENUP_ANGLE);
#endif
}

// Main execution loop
// --------------------------------------
void loop() {
  curTime = micros();
  if (curTime < sliceStartTime) { // protect against 70 minute overflow
    sliceStartTime = 0;
  }

  long curSliceTime = curTime - sliceStartTime;

#ifdef ENABLE_PENUP
  if (penTransitionDirection) {
    UpdatePenTransition(curSliceTime);
    if (!penTransitionDirection) {
      sliceStartTime = curTime;
    }
  } else {
#endif
    // move to next slice if necessary
    while(curSliceTime > TIME_SLICE_US) {
      SetSliceVariables();
      curSliceTime -= TIME_SLICE_US;
      sliceStartTime += TIME_SLICE_US;

#ifdef ENABLE_PENUP
      if (penTransitionDirection) {
        sliceStartTime = curTime;
        return;
      }
#endif
    }

    UpdateStepperPins(curSliceTime);
#ifdef ENABLE_PENUP
  }
#endif

  ReadSerialMoveData();
  RequestMoreSerialMoveData();
}

// Update stepper pins
// --------------------------------------
void UpdateStepperPins(long curSliceTime) {
  long leftTarget = ((long(leftDelta) * curSliceTime) >> TIME_SLICE_US_LOG) + leftStartPos;
  long rightTarget = ((long(rightDelta) * curSliceTime) >> TIME_SLICE_US_LOG) + rightStartPos;

  int leftSteps = (leftTarget - leftCurPos) >> POS_FACTOR_LOG;
  int rightSteps = (rightTarget - rightCurPos) >> POS_FACTOR_LOG;

  boolean leftPositiveDir = true;
  if (leftSteps < 0) {
    leftPositiveDir = false;
    leftSteps = -leftSteps;
  }
  boolean rightPositiveDir = true;
  if (rightSteps < 0) {
    rightPositiveDir = false;
    rightSteps = -rightSteps;
  }

  do {
    if (leftSteps) {
      forwarda();                        // changed the function
      if (leftPositiveDir) {
        leftCurPos += POS_FACTOR;
      } else {
        leftCurPos -= POS_FACTOR;
      }
      leftSteps--;

      UpdateStatusLeds(leftCurPos >> 13);
    }

    if (rightSteps) {
      forwardb();                        // changed the function
      if (rightPositiveDir) {
        rightCurPos += POS_FACTOR;
      } else {
        rightCurPos -= POS_FACTOR;
      }
      rightSteps--;
    }

    if (leftSteps || rightSteps) {
      delayMicroseconds(50); // delay a small amount of time before refiring the steps to smooth things out
    } else {
      break;
    }
  } while(true);
}

// Update pen position
// --------------------------------------
#ifdef ENABLE_PENUP
void UpdatePenTransition(long curSliceTime) {

  //int targetAngle = ((float)(PENDOWN_ANGLE - PENUP_ANGLE) * ((float)curSliceTime / (float)PENUP_TRANSITION_US)) + PENUP_ANGLE;
  //if (targetAngle > PENDOWN_ANGLE) {
    //targetAngle = PENDOWN_ANGLE;

    if (curSliceTime > PENUP_COOLDOWN_US) {
      penTransitionDirection = 0; // are done moving the pen servo
    }
  //}

  if (penTransitionDirection == 1) {
	//targetAngle = 180 - targetAngle;
    penUpServo.write(PENUP_ANGLE);
  } else if (penTransitionDirection == -1) {
    penUpServo.write(PENDOWN_ANGLE);
  }

  //penUpServo.write(targetAngle);
}
#endif

// Update status leds
// --------------------------------------
void UpdateStatusLeds(int value) {
  // output the time to the leds in binary
  digitalWrite(LED_PINS[0], value & 0x1);
  digitalWrite(LED_PINS[1], value & 0x2);
  digitalWrite(LED_PINS[2], value & 0x4);
}

// Update receive leds
// --------------------------------------
void UpdateReceiveLed(boolean value) {
  digitalWrite(LED_PINS[3], value);
}

// Set all variables based on the data currently in the buffer
// --------------------------------------
void SetSliceVariables() {
  // set slice start pos to previous slice start plus previous delta
  leftStartPos = leftStartPos + long(leftDelta);
  rightStartPos = rightStartPos + long(rightDelta);

  if (moveDataLength < 2) {
    leftDelta = rightDelta = 0;
  } else {
    leftDelta = MoveDataGet();
    rightDelta = MoveDataGet();

#ifdef ENABLE_PENUP
    if (leftDelta == PENUP_COMMAND) {
      leftDelta = rightDelta = 0;
      penTransitionDirection = 1;
    } else if (leftDelta == PENDOWN_COMMAND) {
      leftDelta = rightDelta = 0;
      penTransitionDirection = -1;
    }
#else
    if (leftDelta == PENUP_COMMAND || leftDelta == PENDOWN_COMMAND) {
       leftDelta = rightDelta = 0;
    }
#endif
  }
}                                                                                                                                                                                                                                                                                                                                                                                                                                                                                                                                                                                                                                                                                                                                                                                                                                                                                                                                                                                                                                                                                                                                                                                                                                                                                                                                                                                                                                                                                                                                                                                                                                                                                                                                                                                                                                                                                                                                                                                                                                            

// Stop everything and blink the status led value times
// --------------------------------------
void Blink(char value) {
 int counts = value;
  if (counts<0) counts=-counts;

  UpdateReceiveLed(false);
  for(int i=0;i<counts;i++) {
   delay(1000);
   UpdateReceiveLed(true);
   delay(1000);
   UpdateReceiveLed(false);

  }
  delay(100000);
}

// Read serial data if its available
// --------------------------------------
void ReadSerialMoveData() {

  if(Serial.available()) {
    char value = Serial.read();

    // Check if this value is the sentinel reset value
    if (value == RESET_COMMAND) {
      ResetMovementVariables();
      moveDataRequestPending = 0;
      moveDataLength = 0;
      UpdateReceiveLed(false);
      return;
    }

    MoveDataPut(value);
    moveDataRequestPending--;

    if (!moveDataRequestPending) {
      UpdateReceiveLed(false);
    }
  }
}

// Put a value onto the end of the move data buffer
// --------------------------------------
void MoveDataPut(char value) {
  int writePosition = moveDataStart + moveDataLength;
  if (writePosition >= MOVE_DATA_CAPACITY) {
    writePosition = writePosition - MOVE_DATA_CAPACITY;
  }

  moveData[writePosition] = value;

  if (moveDataLength == MOVE_DATA_CAPACITY) { // full, overwrite existing data
    moveDataStart++;
    if (moveDataStart == MOVE_DATA_CAPACITY) {
      moveDataStart = 0;
    }
  }
  else {
    moveDataLength++;
  }
}
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
brianinnes, 2016-04-14:
This is not a bug in the project code, so I am closing the issue.  I've not got a motor shield, but a quick web search shows it uses pins D12 & D13 for the direction control and D3 and D11 for the steps.  Your sketch configures the LED pins as 10, 11, 12 and 13 which will conflict with the motor control pins?

Closed 2016-04-14.

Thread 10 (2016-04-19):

Units should be in mm

MarkJB, 2016-04-19:
This is an Enhancement request. Might be irrelevant in light of the pending work, but raising it anyway as it is worth some consideration.

It is difficult to work in pixels when using multiple machines with different page sizes.

It would make life easier if units were in mm.

brianinnes, 2016-04-19:
In the config just set the pixels value to the same as the paper width (in mm) then the measurements are in mm.

MarkJB, 2016-04-19:
Does that not affect the 'resolution' of the pixels?

brianinnes, 2016-04-19:
depends.  If you always make the pixel size 1 mm square (pixel size in line with the paper size), then the number of pixels in each direction will change as paper size changes.  If you leave the pixel size the same across all the different paper size, then each paper size will have a scaled pixel size, but there will be the same number of pixels across the page.

Current implementation allows either way of working, but some of my test apps assume a 5000 pixel width.

Closed 2016-04-19.

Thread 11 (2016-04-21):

Default servo settings nearly cooked a servo

MarkJB, 2016-04-21:
I uploaded the vPiP arduino/stepper firmware to a pro mini and the servo did the usual up-down-up move. After a few minutes the servo was too hot to touch. I think the default values had this servo straining against its mechanical limits.

I'm wondering if this was what cooked the servo and arduino on the middle machine in the library.

Need to have default servo values that are nearer the middle of the range and with less travel between them to avoid risking damage.

brianinnes, 2017-09-11:
Fixed in v2 : The servo limits are no longer hard coded in the Arduino firmware.  Values can be set on the Pi and are sent to the Arduino at startup. 37af6e78de0516c9e5431b9141468f667e025eab

Closed 2017-09-11.

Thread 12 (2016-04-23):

Have to reset Arduino to get things working (vPiP board v1.0b)

MarkJB, 2016-04-23:
When I run vPiP (python test1.py) on a vPiP board v1.0b, the program sits at Polargraph exit until I reset the Arduino Pro Mini at which point the servo does its down-up-down move and then the steppers work...

I opened this against the vPiP board, but have done some debugging on the Arduino firmware and I think the issue is on the vPiP software side, so creating new issue here.

https://github.com/MarkJB/pi-2-stepper-board/issues/6

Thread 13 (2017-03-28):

Glitchy, stop/start steppers

MarkJB, 2017-03-28:
I thought this was only affecting my machine, but we were seeing this at the last meetup on another machine.

The steppers are stop-start with the following error repeatedly shown on the console:

Step handler thread exception : <class 'serial.serialutil.SerialException'>
  File "/home/mark/Documents/github/vPiP/python/vPiP/serialHandler.py", line 106, in _stepHandlerThread
    dataRead = self.serialPort.read()
  File "/usr/lib/python2.7/dist-packages/serial/serialposix.py", line 495, in read
    raise SerialException('device reports readiness to read but returned no data (device disconnected or multiple access on port?)')

I'm also seeing this when run from Linux Mint 18.1

I found the issue mentioned here: https://github.com/pyserial/pyserial/issues/17

MarkJB, 2017-03-29:
If I use alt:///dev/usbX?class=VTIMESerial then the errors stop, but the steppers are still glitchy...

I changed the following:
`#from serial import Serial`
`import serial`

`    def connect(self):`
`        # self.serialPort = Serial(self.config.serialPort, self.config.baud, timeout=10)`
`        self.serialPort = serial.serial_for_url('alt://' + self.config.serialPort + '?class=VTIMESerial', timeout=10)`
`        self.serialPort.baudrate = self.config.baud`

I'm also seeing two instances of `Starting stepHandlerThread` ?!?

`Starting stepHandlerThread`
`Connected to Vpip`
`Starting stepHandlerThread`
`Connected to Vpip`
`Vpip __exit__`

MarkJB, 2017-04-18:
The issue wasn't pyserial, it was due to multiple serial processes starting up.

One created by a line in the config: polardraw = True
The other in the calling python script: p.setPlotting(True)

Added Brians 'on the fly' fix in commit 153e3c0b294d1045a9eb5ccc3e128b42176718a8

Closed 2017-04-18.

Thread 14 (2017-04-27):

Define v2 architecture

brianinnes, 2017-04-27:

brianinnes, 2017-04-27:
Need to be able to compile C/C++ code for:

- Raspberry Pi Zero/B+
- Raspberry Pi 3
- Arduino

Must be cross platform (Windows, Linux, MacOS)

brianinnes, 2017-09-10:
https://github.com/brianinnes/vPiP/wiki/architecture

Closed 2017-09-10.

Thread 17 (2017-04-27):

Implement Stepper Driver

brianinnes, 2017-04-27:

brianinnes, 2017-04-27:
Implement the stepper driver for Raspberry Pi Zero / 3b in C++ to drive the Arduino program, which in turn drives the stepper motors.  The Raspberry Pi and Arduino should communicate via serial.

This functionality removes the python equivalent code from V1, but uses the message bus for communication

brianinnes, 2017-09-10:
This is now the board driver in V0.2 and the communication is over I2C rather than serial

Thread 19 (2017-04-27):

Create documentation on setting up Mosquitto message broker

brianinnes, 2017-04-27:

brianinnes, 2017-04-27:
Assumption is that this will initial run on a Raspberry Pi - is this correct?
Do we need a Docker container for running on laptops?
Do we need to support a cloud service?

MarkJB, 2017-04-27:
It would be useful to be able to run the software on a laptop/PC as well as the Raspberry Pi.

Assuming the rest of the software can be made to run on a PC as well (i.e. the serial comms module). Is the software tied to a specific message broker in any way? (i.e. can we not just swap out one message broker for another).

brianinnes, 2017-04-27:
Mosquitto can run on Windows, macOS and Linux.  Unfortunately I don't think there is a universal API that works across message brokers, so focus will be the defacto standard, which is MQTT.  This is what Mosquitto supports in addition to a number of [other servers](https://github.com/mqtt/mqtt.github.io/wiki/servers).  It should be possible to swap out Mosquitto for another server (so long as they don't impose any topic namespace restrictions)

For the stepper driver It is probably safe to assume that other Linux systems will be able to run the software, but would need to add additional build steps (Vagrant build machine is Debian, so all the build tools for 32/64 bit Linux builds are already installed).
Would need to look at comms handling in macOS and Windows to see if they can be supported - the primary goal will be the Raspberry Pi, other platforms will be secondary

brianinnes, 2017-04-27:
Mosquitto can run on Windows, macOS and Linux.  There is no universal message bus API, but MQTT is seen as a defacto standard, which is what Mosquitto supports, in addition to a number of [other servers](https://github.com/mqtt/mqtt.github.io/wiki/servers), so it should be possible to switch out Mosquitto for one of the other brokers (so long as there are no topic space restrictions which are incompatible to our implementation).

For the stepperDrivers it should be possible to run the code on a Linux system.  The build system is based on Debian, so adding i386/x64 builds shouldn't be too difficult.  Will need to look at Windows / macOS comms systems to determine how difficult it will be to support these.

Focus of the initial project will be getting everything working on Raspberry Pi, other platforms will be secondary

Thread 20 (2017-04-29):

Complete SVG renderer path commands

brianinnes, 2017-04-29:
Currently the following path commands are not implemented:
- a and A are elliptical arc curves
- q and Q are quadratic bezier curves
- t and T are short and smooth quadratic bezier curves

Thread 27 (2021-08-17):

Drawings appear skewed in shape of cone

sumodnandanwar, 2021-08-17:
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
Hi,
I have built a vertical plotter for huge walls. However my drawings appear horizontally skewed , especially long rectangles as you can see in the attached image. It would be great if you could point me towards potential problems in my setup. Is the trapezoidal interpolator the reason? if yes how can I bypass it?

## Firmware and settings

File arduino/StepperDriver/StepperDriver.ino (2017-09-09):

#include <Wire.h>

// comment out to disable PENUP support
#define ENABLE_PENUP

#define I2C_ADDRESS 8

struct config_t {
    struct pins_t {
        unsigned char stepperEnable;
        unsigned char leftStep;
        unsigned char rightStep;
        unsigned char leftDir;
        unsigned char rightDir;
        unsigned char microSteppingM0;
        unsigned char microSteppingM1;
        unsigned char microSteppingM2;
        unsigned char penServo;
        unsigned char leftStopSense;
        unsigned char rightStopSense;
    } pins;
    unsigned char penUpAngle;
    unsigned char penDownAngle;
    bool autohome;
    unsigned char microSteppingM0;
    unsigned char microSteppingM1;
    unsigned char microSteppingM2;
    short senseTimeout;
    short senseTrigger;
} controllerConfig;

#ifdef ENABLE_PENUP
#include <Servo.h>
Servo penUpServo;
char penTransitionDirection; // -1, 0, 1
const long PENUP_TRANSITION_US = 524288; // time to go from pen up to down, or down to up
const int PENUP_TRANSITION_US_LOG = 19; // 2^19 = 524288
const long PENUP_COOLDOWN_US = 1250000;
#endif

const unsigned int TIME_SLICE_US = 2048; // number of microseconds per time step
const unsigned int TIME_SLICE_US_LOG = 11; // log base 2 of TIME_SLICE_US
const unsigned int POS_FACTOR = 8; // fixed point factor each position is multiplied by
const unsigned int POS_FACTOR_LOG = 3; // log base 2 of POS_FACTOR, used after multiplying two fixed point numbers together

const char RESET_COMMAND = 0x80; // -128, (128) command to reset
const char PENUP_COMMAND = 0x81; // -127, (129) command to lift pen
const char PENDOWN_COMMAND = 0x7F; // 127,(127) command to lower pen

const unsigned char MOVE_DATA_CAPACITY = 255;
char moveData[MOVE_DATA_CAPACITY]; // buffer of move data, circular buffer
unsigned char moveDataStart = 0; // where data is currently being read from
unsigned char moveDataLength = 0; // the number of items in the moveDataBuffer
unsigned char moveDataRequestPending = 0; // number of bytes requested

char leftDelta, rightDelta; // delta in the current slice
long leftStartPos, rightStartPos; // start position for this slice
long leftCurPos, rightCurPos; // current position of the spools

unsigned long curTime; // current time in microseconds
unsigned long sliceStartTime; // start of current slice in microseconds

void receiveI2CEvent(int count);
void requestI2CEvent();

// setup
// --------------------------------------
void setup() {
  Serial.begin(57600);

  // Start I2C connection
  Wire.begin(I2C_ADDRESS);
  Wire.onReceive(receiveI2CEvent);
  Wire.onRequest(requestI2CEvent);
  ResetMovementVariables();

  Serial.println("Stepper Driver");
}

void readConfiguration() {
  int length = sizeof(controllerConfig);
  unsigned char *buff = (void *)&controllerConfig;
  for (int i = 0; i < length; i++) {
    if (Wire.available()) {
      buff[i] = Wire.read();
    }
  }

  pinMode(controllerConfig.pins.microSteppingM0, OUTPUT);
  pinMode(controllerConfig.pins.microSteppingM1, OUTPUT);
  pinMode(controllerConfig.pins.microSteppingM2, OUTPUT);
  digitalWrite(controllerConfig.pins.microSteppingM0, controllerConfig.microSteppingM0);
  digitalWrite(controllerConfig.pins.microSteppingM1, controllerConfig.microSteppingM1);
  digitalWrite(controllerConfig.pins.microSteppingM2, controllerConfig.microSteppingM2);

  pinMode(controllerConfig.pins.leftStep, OUTPUT);
  pinMode(controllerConfig.pins.leftDir, OUTPUT);
  pinMode(controllerConfig.pins.rightStep, OUTPUT);
  pinMode(controllerConfig.pins.rightDir, OUTPUT);
  pinMode(controllerConfig.pins.stepperEnable, OUTPUT);
  digitalWrite(controllerConfig.pins.stepperEnable, LOW);

  pinMode(controllerConfig.pins.leftStopSense, OUTPUT);
  pinMode(controllerConfig.pins.rightStopSense, OUTPUT);
  digitalWrite(controllerConfig.pins.leftStopSense, HIGH);
  digitalWrite(controllerConfig.pins.rightStopSense, HIGH);
#ifdef ENABLE_PENUP
  penUpServo.attach(controllerConfig.pins.penServo);
  penUpServo.write(controllerConfig.penUpAngle);
  delay(1000);
  penUpServo.write(controllerConfig.penDownAngle);
  delay(1000);
  penUpServo.write(controllerConfig.penUpAngle);
  penTransitionDirection = 0;
#endif
  if (controllerConfig.autohome) {
    digitalWrite(controllerConfig.pins.stepperEnable, LOW);
    AutoHome();
  }
}

void receiveDataByte() {
  unsigned char dataByte = 0;
  if (Wire.available()) {
    dataByte = Wire.read();
    MoveDataPut(dataByte);
  }
}

void readDataBlock() {
  while(Wire.available()) {
    unsigned char dataByte = Wire.read();
    MoveDataPut(dataByte);
  }
}

void receiveI2CEvent(int count) {
  unsigned char action;
  if (Wire.available()){
    action = Wire.read();
    switch (action) {
      case 0x00 :
        readConfiguration();
        break;
       case 0x80:
        receiveDataByte();
        break;
       case 0x81:
        break;
       case 0x82:
        readDataBlock();
       default :
        break;
    }
  }
}

void requestI2CEvent() {
  Wire.write(moveDataLength);
}

// Reset all movement variables
// --------------------------------------
void ResetMovementVariables()
{
  leftDelta = rightDelta = leftStartPos = rightStartPos = leftCurPos = rightCurPos = 0;
  sliceStartTime = curTime;
}

// Main execution loop
// --------------------------------------
void loop() {
  curTime = micros();
  while (true) {
    delayMicroseconds(100);
  }
  /*
  if (curTime < sliceStartTime) { // protect against 70 minute overflow
    sliceStartTime = 0;
  }

  long curSliceTime = curTime - sliceStartTime;

#ifdef ENABLE_PENUP
  if (penTransitionDirection) {
    UpdatePenTransition(curSliceTime);
    if (!penTransitionDirection) {
      sliceStartTime = curTime;
    }
  } else {
#endif
    // move to next slice if necessary
    while(curSliceTime > TIME_SLICE_US) {
      SetSliceVariables();
      curSliceTime -= TIME_SLICE_US;
      sliceStartTime += TIME_SLICE_US;

#ifdef ENABLE_PENUP
      if (penTransitionDirection) {
        sliceStartTime = curTime;
        return;
      }
#endif
    }

    UpdateStepperPins(curSliceTime);
#ifdef ENABLE_PENUP
  }
#endif

//  ReadSerialMoveData();
//  RequestMoreSerialMoveData();
*/

}

// Update stepper pins
// --------------------------------------
void UpdateStepperPins(long curSliceTime) {
  long leftTarget = ((long(leftDelta) * curSliceTime) >> TIME_SLICE_US_LOG) + leftStartPos;
  long rightTarget = ((long(rightDelta) * curSliceTime) >> TIME_SLICE_US_LOG) + rightStartPos;

  int leftSteps = (leftTarget - leftCurPos) >> POS_FACTOR_LOG;
  int rightSteps = (rightTarget - rightCurPos) >> POS_FACTOR_LOG;

  boolean leftPositiveDir = true;
  if (leftSteps < 0) {
    leftPositiveDir = false;
    leftSteps = -leftSteps;
  }
  boolean rightPositiveDir = true;
  if (rightSteps < 0) {
    rightPositiveDir = false;
    rightSteps = -rightSteps;
  }

  do {
    if (leftSteps) {
      Step(controllerConfig.pins.leftStep, controllerConfig.pins.leftDir, leftPositiveDir);
      if (leftPositiveDir) {
        leftCurPos += POS_FACTOR;
      } else {
        leftCurPos -= POS_FACTOR;
      }
      leftSteps--;

//      UpdateStatusLeds(leftCurPos >> 13);
    }

    if (rightSteps) {
      Step(controllerConfig.pins.rightStep, controllerConfig.pins.rightDir, rightPositiveDir);
      if (rightPositiveDir) {
        rightCurPos += POS_FACTOR;
      } else {
        rightCurPos -= POS_FACTOR;
      }
      rightSteps--;
    }

    if (leftSteps || rightSteps) {
      delayMicroseconds(50); // delay a small amount of time before refiring the steps to smooth things out
    } else {
      break;
    }
  } while(true);
}

// Update pen position
// --------------------------------------
#ifdef ENABLE_PENUP
void UpdatePenTransition(long curSliceTime) {

  //int targetAngle = ((float)(PENDOWN_ANGLE - PENUP_ANGLE) * ((float)curSliceTime / (float)PENUP_TRANSITION_US)) + PENUP_ANGLE;
  //if (targetAngle > PENDOWN_ANGLE) {
    //targetAngle = PENDOWN_ANGLE;

    if (curSliceTime > PENUP_COOLDOWN_US) {
      penTransitionDirection = 0; // are done moving the pen servo
    }
  //}

  if (penTransitionDirection == 1) {
  //targetAngle = 180 - targetAngle;
    penUpServo.write(controllerConfig.penUpAngle);
  } else if (penTransitionDirection == -1) {
    penUpServo.write(controllerConfig.penDownAngle);
  }

  //penUpServo.write(targetAngle);
}
#endif

// Step
// --------------------------------------
void Step(int stepPin, int dirPin, boolean dir) {
  digitalWrite(dirPin, dir);

  digitalWrite(stepPin, LOW);
  digitalWrite(stepPin, HIGH);
}

// Set all variables based on the data currently in the buffer
// --------------------------------------
void SetSliceVariables() {
  // set slice start pos to previous slice start plus previous delta
  leftStartPos = leftStartPos + long(leftDelta);
  rightStartPos = rightStartPos + long(rightDelta);

  if (moveDataLength < 2) {
    leftDelta = rightDelta = 0;
  } else {
    leftDelta = MoveDataGet();
    rightDelta = MoveDataGet();

#ifdef ENABLE_PENUP
    if (leftDelta == PENUP_COMMAND) {
      leftDelta = rightDelta = 0;
      penTransitionDirection = 1;
    } else if (leftDelta == PENDOWN_COMMAND) {
      leftDelta = rightDelta = 0;
      penTransitionDirection = -1;
    }
#else
    if (leftDelta == PENUP_COMMAND || leftDelta == PENDOWN_COMMAND) {
       leftDelta = rightDelta = 0;
    }
#endif
  }
}


// Read serial data if its available
// --------------------------------------
void ReadSerialMoveData() {

  if(Serial.available()) {
    char value = Serial.read();

    // Check if this value is the sentinel reset value
    if (value == RESET_COMMAND) {
      ResetMovementVariables();
      moveDataRequestPending = 0;
      moveDataLength = 0;
      return;
    }

    MoveDataPut(value);
    moveDataRequestPending--;

  }
}

// Put a value onto the end of the move data buffer
// --------------------------------------
void MoveDataPut(char value) {
  int writePosition = moveDataStart + moveDataLength;
  if (writePosition >= MOVE_DATA_CAPACITY) {
    writePosition = writePosition - MOVE_DATA_CAPACITY;
  }

  moveData[writePosition] = value;

  if (moveDataLength == MOVE_DATA_CAPACITY) { // full, overwrite existing data
    moveDataStart++;
    if (moveDataStart == MOVE_DATA_CAPACITY) {
      moveDataStart = 0;
    }
  }
  else {
    moveDataLength++;
  }
}

// Return a piece of data sitting in the moveData buffer, removing it from the buffer
// --------------------------------------
char MoveDataGet() {
  if (moveDataLength == 0) {
    return 0;
  }

  char result = moveData[moveDataStart];
  moveDataStart++;
  if (moveDataStart == MOVE_DATA_CAPACITY) {
    moveDataStart = 0;
  }
  moveDataLength--;

  return result;
}

// Return the amount of data sitting in the moveData buffer
// --------------------------------------
void RequestMoreSerialMoveData() {
  if (moveDataRequestPending > 0 || MOVE_DATA_CAPACITY - moveDataLength < 128)
    return;

  // request 128 bytes of data
  Serial.write(128);
  moveDataRequestPending = 128;
}


void AutoHome() {
  bool rHoming = true;
  bool lHoming = true;

  for (int i = 0; i < 200; i++) {
    Step(controllerConfig.pins.leftStep, controllerConfig.pins.leftDir, 0);
    Step(controllerConfig.pins.rightStep, controllerConfig.pins.rightDir, 1);
   delay(10);
  }

  while (rHoming || lHoming) {
    pinMode(controllerConfig.pins.leftStopSense, INPUT);
    pinMode(controllerConfig.pins.rightStopSense, INPUT);
    digitalWrite(controllerConfig.pins.leftStopSense, LOW);
    digitalWrite(controllerConfig.pins.rightStopSense, LOW);
    unsigned long startTime = micros();
    unsigned long time = micros() - startTime;
    bool lhigh = true;
    bool rhigh = true;
    while ((lhigh || rhigh) && (time < controllerConfig.senseTimeout))
    {
      if (lhigh && lHoming && (digitalRead(controllerConfig.pins.leftStopSense) == LOW)) {
        lhigh = false;
        if (time > controllerConfig.senseTrigger) {
          lHoming = false;
        }
      }
      if (rhigh && rHoming &&(digitalRead(controllerConfig.pins.rightStopSense) == LOW)) {
        rhigh = false;
        if (time > controllerConfig.senseTrigger) {
          rHoming = false;
        }
      }
      time = micros() - startTime;
    }
    pinMode(controllerConfig.pins.leftStopSense, OUTPUT);
    pinMode(controllerConfig.pins.rightStopSense, OUTPUT);
    digitalWrite(controllerConfig.pins.leftStopSense, HIGH);
    digitalWrite(controllerConfig.pins.rightStopSense, HIGH);
    if (lHoming) {
      Step(controllerConfig.pins.leftStep, controllerConfig.pins.leftDir, 1);
    }
    if (rHoming) {
      Step(controllerConfig.pins.rightStep, controllerConfig.pins.rightDir, 0);
    }
    delayMicroseconds(300000);
  }
}

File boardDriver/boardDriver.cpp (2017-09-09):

#include <iostream>
#include <cstdlib>
#include <string>
#include <cstring>
#include <cctype>
#include <thread>
#include <chrono>
#include <mqtt/async_client.h>
#include "vpipController.h"

const std::string ADDRESS("localhost:1883");
const std::string CLIENTID("biPlotter");
const std::string TOPIC("#");

const int  QOS = 1;
const long TIMEOUT = 10000L;

// Board connection variables and constants
#define I2C_ADDRESS 0x08
int file_i2c;
int length;
char buffer[60] = {0};
int i2cSlaveAddr = 0x08;
vpipController *controller = 0;

/////////////////////////////////////////////////////////////////////////////

class action_listener : public virtual mqtt::iaction_listener
{
	std::string name_;

	virtual void on_failure(const mqtt::itoken& tok) {
		std::cout << name_ << " failure";
		if (tok.get_message_id() != 0)
			std::cout << " (token: " << tok.get_message_id() << ")" << std::endl;
		std::cout << std::endl;
	}

	virtual void on_success(const mqtt::itoken& tok) {
		std::cout << name_ << " success";
		if (tok.get_message_id() != 0)
			std::cout << " (token: " << tok.get_message_id() << ")" << std::endl;
		if (!tok.get_topics().empty())
			std::cout << "\ttoken topic: '" << tok.get_topics()[0] << "', ..." << std::endl;
		std::cout << std::endl;
	}

public:
	action_listener(const std::string& name) : name_(name) {}
};

/////////////////////////////////////////////////////////////////////////////

class callback : public virtual mqtt::callback,
					public virtual mqtt::iaction_listener

{
	int nretry_;
	mqtt::async_client& cli_;
	action_listener& listener_;
	vpipController *controller;

	void reconnect() {
		std::this_thread::sleep_for(std::chrono::milliseconds(100));
		mqtt::connect_options connOpts;
		connOpts.set_keep_alive_interval(20);
		connOpts.set_clean_session(true);

		try {
			cli_.connect(connOpts, nullptr, *this);
		}
		catch (const mqtt::exception& exc) {
			std::cerr << "Error: " << exc.what() << std::endl;
			exit(1);
		}
	}

	// Re-connection failure
	virtual void on_failure(const mqtt::itoken& tok) {
		std::cout << "Reconnection failed." << std::endl;
		if (++nretry_ > 5)
			exit(1);
		reconnect();
	}

	// Re-connection success
	virtual void on_success(const mqtt::itoken& tok) {
		std::cout << "Reconnection success" << std::endl;;
		cli_.subscribe(TOPIC, QOS, nullptr, listener_);
	}

	virtual void connection_lost(const std::string& cause) {
		std::cout << "\nConnection lost" << std::endl;
		if (!cause.empty())
			std::cout << "\tcause: " << cause << std::endl;

		std::cout << "Reconnecting." << std::endl;
		nretry_ = 0;
		reconnect();
	}

	virtual void message_arrived(const std::string& topic, mqtt::message_ptr msg) {
		std::cout << "Message arrived" << std::endl;
		std::cout << "\ttopic: '" << topic << "'" << std::endl;
		std::cout << "\t'" << msg->to_str() << "'\n" << std::endl;
	}

	virtual void delivery_complete(mqtt::idelivery_token_ptr token) {}

public:
	callback(mqtt::async_client& cli, action_listener& listener, vpipController *controller)
				: cli_(cli), listener_(listener) {
					this->controller = controller;
				}
};

/////////////////////////////////////////////////////////////////////////////

int main(int argc, char* argv[])
{
	mqtt::async_client client(ADDRESS, CLIENTID);
	action_listener subListener("Subscription");

	controller = new vpipController(I2C_ADDRESS);
	if (0 < controller->openI2C()) {
		printf("Failed to open i2c bus\n");
		exit(EXIT_FAILURE);
	}
	printf("Board connected\n");


	callback cb(client, subListener, controller);
	client.set_callback(cb);

	mqtt::connect_options connOpts;
	connOpts.set_keep_alive_interval(20);
	connOpts.set_clean_session(true);

	try {
		mqtt::itoken_ptr conntok = client.connect(connOpts);
		std::cout << "Waiting for the connection..." << std::flush;
		conntok->wait_for_completion();
		std::cout << "OK" << std::endl;

		std::cout << "Subscribing to topic " << TOPIC << "\n"
			<< "for client " << CLIENTID
			<< " using QoS" << QOS << "\n\n"
			<< "Press Q<Enter> to quit\n" << std::endl;

		client.subscribe(TOPIC, QOS, nullptr, subListener);

		while (std::tolower(std::cin.get()) != 'q')
			;

		std::cout << "Disconnecting..." << std::flush;
		conntok = client.disconnect();
		conntok->wait_for_completion();
		std::cout << "OK" << std::endl;
	}
	catch (const mqtt::exception& exc) {
		std::cerr << "Error: " << exc.what() << std::endl;
		return 1;
	}

 	return 0;
}

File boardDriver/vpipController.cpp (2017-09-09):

#include "vpipController.h"
#include <unistd.h>
#include <stdio.h>
#include <cstring>
#include <iostream>
#include <fcntl.h>
#include <sys/ioctl.h>
#include <linux/i2c.h>
#include <linux/i2c-dev.h>

vpipController::vpipController(unsigned char address) {
    this->devAddr = address;
    this->i2cFileDesc = 0;
    this->setDefaultConfig();
    printf("Size of config = %d\n", sizeof(this->controllerConfig));
}

vpipController::~vpipController() {
    this->closeI2C();
}

int vpipController::openI2C() {
    if (0 != this->i2cFileDesc) {
        closeI2C();
    }
    this->i2cFileDesc = open("/dev/i2c-1", O_RDWR);
    if(this->i2cFileDesc < 0){
        printf("Could not open I2C connection\n");
        return 1;
    }
    if (ioctl(this->i2cFileDesc, I2C_SLAVE, this->devAddr) < 0) {
        printf("Failed to acquire bus access\n");
        return 2;
    }
    sendConfigToController();
    return 0;
}

void vpipController::closeI2C() {
    if (0 != this->i2cFileDesc) {
        close(this->i2cFileDesc);
        this->i2cFileDesc = 0;
    }
}

unsigned char vpipController::sendByte(unsigned char data) {
    unsigned char queueLength = 0;
    unsigned char buff[2];
    buff[0] = DATA_BYTE;
    buff[1] = data;
    this->sendToControllerResponse(buff, 2, &queueLength, 1);
    return queueLength;
}

unsigned char vpipController::getQueueLength() {
    unsigned char queueLength = 0;
    unsigned char buff = DATA_CAPACITY;
    this->sendToControllerResponse(&buff, 1, &queueLength, 1);
    return queueLength;
}

unsigned char vpipController::sendDataBlock(unsigned char *data, int length){
    unsigned char queueLength = 0;
    int sendLength = length + 1;
    unsigned char buff[length];
    buff[0] = DATA_BLOCK;
    memcpy(buff+1,data, length);
    this->sendToControllerResponse(buff, sendLength, &queueLength, 1);
    return queueLength;
}


void vpipController::setDefaultConfig() {
    this->controllerConfig.pins.stepperEnable = 9;
    this->controllerConfig.pins.leftStep = 3;
    this->controllerConfig.pins.leftDir = 2;
    this->controllerConfig.pins.rightStep = 5;
    this->controllerConfig.pins.rightDir = 4;
    this->controllerConfig.pins.microSteppingM0 = 8;
    this->controllerConfig.pins.microSteppingM1 = 7;
    this->controllerConfig.pins.microSteppingM2 = 6;
    this->controllerConfig.pins.penServo = 14;
    this->controllerConfig.pins.leftStopSense = 16;
    this->controllerConfig.pins.rightStopSense = 15;
    this->controllerConfig.penUpAngle = 170;
    this->controllerConfig.penDownAngle = 85;
    this->controllerConfig.autohome = true;
    this->controllerConfig.microSteppingM0 = 0;
    this->controllerConfig.microSteppingM1 = 1;
    this->controllerConfig.microSteppingM2 = 0;
    this->controllerConfig.senseTimeout = 2500;
    this->controllerConfig.senseTrigger = 250;
}

int vpipController::sendToControllerNoResponse(unsigned char*data, int length) {
    struct i2c_rdwr_ioctl_data pkt;
    struct i2c_msg msg[1];
    msg[0].addr = this->devAddr;
    msg[0].flags = 0;
    msg[0].len = length;
    msg[0].buf = data;
    pkt.msgs = msg;
    pkt.nmsgs = 1;

    int ret = ioctl(this->i2cFileDesc, I2C_RDWR, &pkt);
    if (0 > ret) {
        printf("Write to I2C device failed : %d - %s\n", ret, strerror(errno));
    }
    return ret;
}

int vpipController::sendToControllerResponse(unsigned char *data, int length, unsigned char *resp, int rLength) {
    struct i2c_rdwr_ioctl_data pkt;
    struct i2c_msg msg[2];
    msg[0].addr = this->devAddr;
    msg[0].flags = 0;
    msg[0].len = length;
    msg[0].buf = data;
    msg[1].addr = this->devAddr;
    msg[1].flags = I2C_M_RD;
    msg[1].len = rLength;
    msg[1].buf = resp;
    pkt.msgs = msg;
    pkt.nmsgs = 2;

    int ret = ioctl(this->i2cFileDesc, I2C_RDWR, &pkt);
    if (0 > ret) {
        printf("Write with response to I2C device failed : %d - %s\n", ret, strerror(errno));
    }
    return ret;
}



void vpipController::sendConfigToController() {
    int length = sizeof(this->controllerConfig) + 1;
    unsigned char buff[length];
    buff[0] = CONFIG_ALL;
    memcpy(buff+1,(void*)&this->controllerConfig, sizeof(this->controllerConfig));
    this->sendToControllerNoResponse(buff, length);
}

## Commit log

2016-03-09 Moved from using threads to use multiprocesses to get round single process restriction and enable use of multi-core raspberry pi
2017-09-04 3d print files for Desktop version of vPiP machine
    [BearingPullyWheel.stl, CableGrab] (1).stl, CordArm.stl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]
2017-09-09 Initial commit - added I2C, moved all config into Pi and autohome
    [HangarCableGrab.stl, Motor cog (1).stl, WheelBearing.stl]
2018-01-11 Document planning new movement planning and stepper driving algorithm
2018-04-13 Changed library to use MQTT rather than serial connection to board - #23
2018-08-05 script to install on Raspberry Pi
